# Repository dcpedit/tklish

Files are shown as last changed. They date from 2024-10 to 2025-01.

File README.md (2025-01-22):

# TKLish

TKLish keyboards

TKLish is a series of PCBS that mimic the style of a traditional TLK (Ten Key Less) keyboard.  Below are the 3 variants:

* s40 - 40% layout with staggered keys. [KLE layouts](https://www.keyboard-layout-editor.com/#/gists/37cd11a38042b60f3afcef27ad9ed609)
* o40 - 40% layout with ortholinear keys. [KLE layouts](https://www.keyboard-layout-editor.com/#/gists/dfc48e95a2b35d166118a279e23edf5c)
* o80 - 80% layout with ortholinear keys. [KLE layouts](https://www.keyboard-layout-editor.com/#/gists/64b1c8ef28d2a8a90b8a3357935d477c)

Features:

* s40 can use standard keycaps (no 40s kit required)
* s40 & o80 can utilize any ergo/ergodox kit with 1.5u modifier keys (ex. GMK Sixes, SA Carbon)
* PCB can support up to 3 rotary encoders
* Utilizes Unified Daughterboard (C4 version with Molex Pico-EZmate connectors)

The o80 PCB should work with any case that does require the PCB to be mounted (PCB has no mounting holes) and utilizes a USB-C daughterboard.  I've only been able to test it with the Thecca x Rubrehose case.

## Stacked Acrylic Case

TKLish 40s case

I've designed a stacked acrylic case that works with the 40% PCBs.  You can look at the build guide in the [case](./case/README.md) directory.

## Firmware

Vial source code located here:

https://github.com/dcpedit/vial-qmk/blob/tklish/keyboards/dcpedit/tklish/

Vial: https://get.vial.today

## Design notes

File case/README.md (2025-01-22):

TKLish 40s boards

This guide is for building a case for the TKLish s40 & o40 PCBs

## Components

| Part | Count | Description |
| ---- | ----- | --- |
| USB-C daughterboard | 1 | [C4 Unified](https://cannonkeys.com/products/unified-daughterboard-and-jst-cable?variant=41613867810927) |
| 170mm connector | 1 | Molex Pico-EZmate Connector on both ends |
| Hot swap sockets | 59-69 | Kailh, or Gatern v2 |
| Caps lock LED | 1 | |
| Caps lock resistor | 1 | 1k -10k|
| Rotary encoder | 0 - 3 | EC11 |
| Encoder knob | 0 - 3 | 18mm diameter |
| Plate foam | 1-2 | 3.5mm (or 1.5mm + 2mm) EVA |
| Switch plate | 1 | 1.5mm or 3mm acrylic |
| Stabalizers | 0 - 6 | PCB mount |
| Acrylic case layers | 7-8 | Including switch plate
| M2x24mm standoff | 4 | Case perimeter (upper) |
| M2x13mm standoff | 4 | Case perimeter (lower) |
| M2x6mm screw | 8 | Case bottom |
| M2x8mm screw | 8 | Case top |
| Double-sided foam tape | 1 | <= 1mm thick |
| Adhesive bumpers | 4 | 8mm diameter |

## Case Layers
These are the layers that are labeled in the Illustrator file.  All the layer should be 3mm in thickness except for #4a and #4b, which are 1.5mm. 

| Layer Name | Count | Description |
| ---- | ----- | --- |
| #1 Top Layer | 1 | 3mm thickness |
| #2 - #3 Top Spacers | 2 | 3mm thickness |
| #4a Plate 1.5mm | 1 | 1.5mm thickness |
| #4b Plate Spacer 1.5mm | 1 | 1.5mm thickness |
| #5 Bottom Spacer | 1 | 3mm thickness |
| #6 Bottom Spacer | 1 | 3mm thickness |
| #7 Bottom | 1 | 3mm thickness |
| #8 Feet4 | 1 | 3mm thickness |
| #9 Feet3 | 1 | 3mm thickness |
| #10 Feet2 | 1 | 3mm thickness |
| #11 Feet1 | 1 | 3mm thickness |
| Foam Plate 3.5mm | 1-2 | 3.5mm (or 1.5mm + 2mm) EVA |

## Assembly Steps

### Solder switch sockets

Place some solder on one of the hot swap socket pads.  There should ben enough solder to make a small mound.  Place the socket into position and melt the mound of solder that was previously added while pressing down on the center of the socket.  Be sure to avoid touching any metalic parts to prevent burns.  Keep the soldering iron on the pad long enough for the solder to flow around the socket connector (usually around 3 to 4 seconds).  Now solder the other socket connector to the pad.

### Solder rotary encoders

Insert rotary into the front of the PCB, solder, and clip off the pins with a flush cutter.

### Install stabalizers

The number and size of the stabalizers will vary based on your chosen layout.

### Assemble plate, plate foam, and switches

If you're using a 3mm plate, you can optionally use 2mm plate foam.  If you're using a 1.5mm plate + 1.5mm spacer, you can optionally use 3.5mm plate foam.  Line up the plate foam on top of your PCB if you're using it, and line up the switch plate on top of the foam.  Then insert your switches, making sure they are fully seated against the switch plate (no gaps).

## Case Assembly

### Layer #11

layer11

Attach 4 M2x24mm standoffs to this layer with 4 M2x6mm screws.

### Layers #7-10

layers7-10

Line the top holes up with the standoffs and place the layers on top.  Attach 4 M2x13mm standoffs to the bottom of layer #7 with 4 M2x6mm screws.

### USB-C Daughterboard

foam tape

Cut a small piece of foam tape and attach it to the bottom of the daughterboard.

### Attach Daughterboard

attached daughterboard

Expose the other side of the adhesive and press the daughterboard into the slot.

### Daughterboard Cable

daughterboard cable

Attach one end of the cable to the daughterboard and loop any extra inside the cable cutout.

### Spacer Layers #5 - 6

Slide these spacer layers by ligning up the standoffs with the holes.

### Switch Plate Layer #4

If you're using a 1.5mm switch plate, you will need to place the 1.5mm spacer in first.  Then place your assembled switch plate on top.

### Layer #1 - 3

Line up the remaining layers with the standoffs and stack them on top.

### Top screws

top screws

Use 8 M2x8mm screws to fasten the top to the standoffs.

### Adhesive bumpers

adhesive bumpers

You can add adhesive bumpers to the corners of the bottom

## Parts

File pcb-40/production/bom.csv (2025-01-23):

Designator | Footprint | Quantity | Value | LCSC Part #
C1, C3, C4, C5, C6, C7 | 0402 | 6 | 100nF | C307331
C2 | 0402 | 1 | 4.7uF | C23733
C8, C9 | 0402 | 2 | 1uF | C52923
D10, D100, D102, D103, D104, D105, D12, D13, D14, D15, D16, D18, D19, D20, D21, D22, D24, D25, D26, D27, D28, D30, D31, D32, D33, D34, D36, D37, D38, D39, D40, D42, D43, D44, D58, D60, D61, D62, D63, D64, D66, D67, D68, D70, D72, D73, D74, D75, D76, D78, D79, D80, D81, D82, D84, D85, D86, D87, D88, D90, D91, D94, D97, D98, D99 | D_SOD-123 | 65 | ~ | C81598
J1 | MOLEX_781710004_MountingReliefs | 1 | JST | C588524
MX10, MX100, MX102, MX103, MX104, MX105, MX16, MX18, MX19, MX20, MX21, MX22, MX24, MX25, MX26, MX27, MX28, MX30, MX31, MX32, MX33, MX34, MX36, MX37, MX38, MX40, MX42, MX43, MX44, MX58, MX60, MX61, MX62, MX64, MX66, MX67, MX68, MX70, MX72, MX73, MX74, MX75, MX76, MX78, MX79, MX80, MX81, MX82, MX84, MX85, MX88, MX97, MX98, MX99 | MXOnly-1U-Hotswap | 54 | MX-NoLED
MX12, MX15.15, MX21.15, MX81.15, MX87.15, MX90 | MXOnly-1.5U-Hotswap | 6 | MX-NoLED
MX13 | MXOnly-1.75U-Hotswap-LED | 1 | MX-LED
MX13.125 | MXOnly-1.25U | 1 | MX-LED
MX14, MX85_2 | MXOnly-2.25U-Hotswap | 2 | MX-NoLED
MX14.125, MX15, MX87, MX91 | MXOnly-1.25U-Hotswap | 4 | MX-NoLED
MX39 | MXOnly-7U-Hotswap-ReversedStabilizers | 1 | MX-NoLED
MX39.275 | MXOnly-2.75U-Hotswap-ReversedStabilizers | 1 | MX-NoLED
MX63 | MXOnly-2.25U-Hotswap-ReversedStabilizers | 1 | MX-NoLED
MX86 | MXOnly-2.75U-Hotswap | 1 | MX-NoLED
MX86.175 | MXOnly-1.75U-Hotswap | 1 | MX-NoLED
MX91.2 | MXOnly-ISO-Hotswap | 1 | MX-NoLED
MX94 | MXOnly-1U-Hotswap-LED | 1 | MX-LED
R1 | 0402 | 1 | 10k | C25744
R2, R3 | Resistor-Hybrid-Back | 2 | 470
SW1, SW2 | SW_SPST_SKQG_WithoutStem | 2 | RST | C318884
SWR1, SWR2, SWR3 | RotaryEncoder_EC11_Nonplated | 3 | RotaryEncoder_Switch
U1 | LQFP-48_7x7mm_P0.5mm | 1 | STM32F072C8Tx | C80488
U2 | SOT-23 | 1 | XC6206PxxxMR-Regulator_Linear | C5446

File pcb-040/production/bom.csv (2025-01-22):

Designator | Footprint | Quantity | Value | LCSC Part #
C1, C3, C4, C5, C6, C7 | 0402 | 6 | 100nF | C307331
C2 | 0402 | 1 | 4.7uF | C23733
C8, C9 | 0402 | 2 | 1uF | C52923
D10, D100, D102, D103, D104, D105, D12, D13, D14, D15, D16, D18, D19, D20, D21, D22, D24, D25, D26, D27, D28, D30, D31, D32, D33, D34, D36, D37, D38, D39, D40, D42, D43, D44, D45, D58, D60, D61, D62, D63, D64, D66, D67, D68, D69, D70, D72, D73, D74, D75, D76, D78, D79, D80, D81, D82, D84, D85, D86, D87, D88, D90, D91, D92, D93, D94, D97, D98, D99 | D_SOD-123 | 69 | ~ | C81598
J1 | MOLEX_781710004_MountingReliefs | 1 | JST | C588524
MX10, MX100, MX102, MX103, MX104, MX105, MX16, MX18, MX19, MX20, MX21, MX22, MX24, MX25, MX26, MX27, MX28, MX30, MX31, MX32, MX33, MX34, MX36, MX37, MX38, MX39, MX40, MX42, MX43, MX44, MX45, MX58, MX60, MX61, MX62, MX63, MX64, MX66, MX67, MX68, MX69, MX70, MX72, MX73, MX74, MX75, MX76, MX78, MX79, MX80, MX81, MX82, MX84, MX85, MX86, MX87, MX88, MX97, MX98, MX99 | MXOnly-1U-Hotswap | 60 | MX-NoLED
MX12, MX14, MX15, MX27.15, MX81.15, MX90, MX91, MX92, MX93 | MXOnly-1.5U-Hotswap | 9 | MX-NoLED
MX13 | MXOnly-1.5U-Hotswap-LED | 1 | MX-LED
MX15.125, MX93.125 | MXOnly-1.25U-Hotswap | 2 | MX-NoLED
MX45.2, MX63.2 | MXOnly-2U-Hotswap | 2 | MX-NoLED
MX94 | MXOnly-1U-Hotswap-LED | 1 | MX-LED
R1 | 0402 | 1 | 10k | C25744
R2, R3 | Resistor-Hybrid-Back | 2 | 470
SW1, SW2 | SW_SPST_SKQG_WithoutStem | 2 | RST | C318884
SWR1, SWR2, SWR3 | RotaryEncoder_EC11_Nonplated | 3 | RotaryEncoder_Switch
U1 | LQFP-48_7x7mm_P0.5mm | 1 | STM32F072C8Tx | C80488
U2 | SOT-23 | 1 | XC6206PxxxMR-Regulator_Linear | C5446

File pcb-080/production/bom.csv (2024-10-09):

Designator | Footprint | Quantity | Value | LCSC Part #
C1, C3, C4, C5, C6, C7 | 0402 | 6 | 100nF | C307331
C2 | 0402 | 1 | 4.7uF | C23733
C8, C9 | 0402 | 2 | 1uF | C52923
D10, D100, D101, D102, D103, D104, D105, D11, D12, D13, D14, D15, D16, D17, D18, D19, D20, D21, D22, D23, D24, D25, D26, D27, D28, D29, D30, D31, D32, D33, D34, D35, D36, D37, D38, D39, D40, D41, D42, D43, D44, D45, D46, D47, D48, D49, D50, D51, D52, D53, D54, D55, D56, D57, D58, D59, D60, D61, D62, D63, D64, D65, D66, D67, D68, D69, D70, D71, D72, D73, D74, D75, D76, D77, D78, D79, D80, D81, D82, D83, D84, D85, D86, D87, D88, D89, D90, D91, D92, D93, D94, D95, D96, D97, D98, D99 | D_SOD-123 | 96 | ~ | C81598
J1 | MOLEX_781710004_MountingReliefs | 1 | JST | C588524
MX10, MX100, MX101, MX102, MX103, MX104, MX105, MX16, MX17, MX18, MX19, MX20, MX21, MX22, MX23, MX24, MX25, MX26, MX27, MX28, MX29, MX30, MX31, MX32, MX33, MX34, MX35, MX36, MX37, MX38, MX39, MX40, MX41, MX42, MX43, MX44, MX45, MX46, MX47, MX48, MX49, MX50, MX51, MX52, MX53, MX54, MX55, MX56, MX57, MX58, MX59, MX60, MX61, MX62, MX63, MX64, MX65, MX66, MX67, MX68, MX69, MX70, MX71, MX72, MX73, MX74, MX75, MX76, MX77, MX78, MX79, MX80, MX81, MX82, MX83, MX84, MX85, MX86, MX87, MX88, MX95, MX96, MX97, MX98, MX99 | MXOnly-1U-Hotswap | 85 | MX-NoLED
MX11, MX12, MX14, MX15, MX89, MX90, MX91, MX92, MX93 | MXOnly-1.5U-Hotswap | 9 | MX-NoLED
MX13 | MXOnly-1.5U-Hotswap-LED | 1 | MX-LED
MX48.15, MX50.15, MX54.15, MX56.15 | MXOnly-1.5U-Hotswap-Vertical | 4 | MX-NoLED
MX51.2, MX57.2 | MXOnly-2U-Hotswap | 2 | MX-NoLED
MX94 | MXOnly-1U-Hotswap-LED | 1 | MX-LED
R1 | 0402 | 1 | 10k | C25744
R2, R3 | Resistor-Hybrid-Back | 2 | 470
SW1, SW2 | SW_SPST_SKQG_WithoutStem | 2 | RST | C318884
SWR1, SWR2, SWR3 | RotaryEncoder_EC11_Nonplated | 3 | RotaryEncoder_Switch
U1 | LQFP-48_7x7mm_P0.5mm | 1 | STM32F072C8Tx | C80488
U2 | SOT-23 | 1 | XC6206PxxxMR-Regulator_Linear | C5446

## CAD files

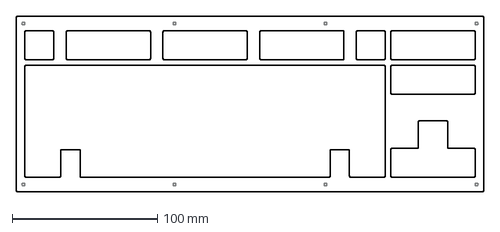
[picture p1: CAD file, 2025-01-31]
case/40.dxf
322.6 x 121.0 mm

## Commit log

2024-12-04 Rev 2 improved layout
    [Matrix.kicad_sch, bom.csv, designators.csv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]
2025-01-22 Update readme and add firmware
    [Matrix.kicad_sch, bom.csv, designators.csv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]
2025-01-22 Fix case link
2025-01-23 Update production files
    [bom.csv, designators.csv, positions.csv]
2025-01-31 Add dxf file
    [40.dxf]
